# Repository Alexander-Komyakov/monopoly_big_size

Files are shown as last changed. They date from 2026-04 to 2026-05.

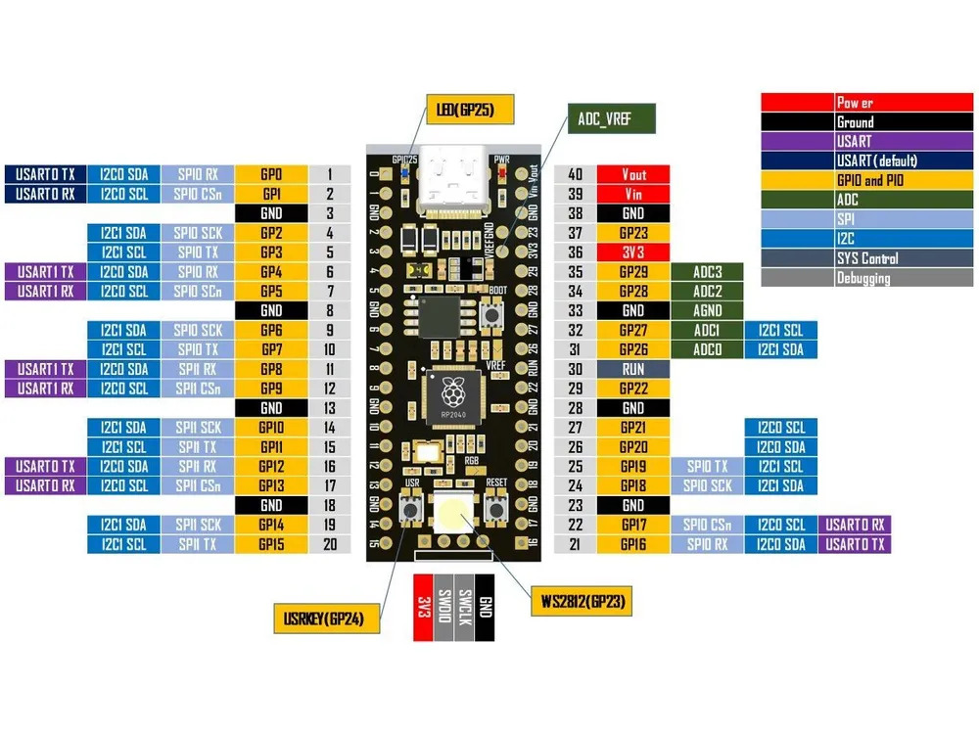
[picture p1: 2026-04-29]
pins.jpg

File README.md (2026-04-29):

# Банк монополии большего размера

Создан для упрощения игры. Вместо подсчета, размена и передачи бумажных купюр используются карточки. Их можно прикладывать для проверки баланса. Добавлять на них деньги, уменьшать или перводить. Для вывода информации используется экран `2,8` дюйма `240x320`. Для чтения карточек `RFID-RC522` и для ввода матричная клавиатура 4x4.

## Детали

- RFID-модуль Arduino RC522 с картой и брелоком 
- Матричная клавиатура 4x4
- Дисплей 2.8" 240x320, SPI
- Контроллер RP2040 TYPE-C 16MB
- Аккумулятор 3.3V 1000mAh
- TP4056 для безопасной зарядки/разрядки
- Переключатель трехконтактный

## Сборка

Зажимаем клавишу boot на rp2040 и подключаем usb. В ОС появится блочное устройство. Копируем на него firmware.uf2

Для сборки проекта устанавливаем python и зависимости из requirements.txt с помощью pip; `pip install -r requirements.txt`. Подключаем по microusb к компьютеру rp2040, при запуске зажимаем клавишу usr на 3 секунды. В системе появится девай `/dev/ttyACM0`
Далее с помощью mpremote копируем файлы на rp2040:
```
mpremote cp keypad.py :keypad.py
mpremote cp mfrc522.py :mfrc522.py
mpremote cp main.py :main.py
```

## Пайка

### Матричная панель

Слева направо напрямую подключаем пины к `rp2040` в `gp0,4,5,6,7,13,14,15`

### Дисплей

- VCC - 3.3V

- GND - GND

- LED = GP21

- RESET = GP20

- DC = GP12

- CS = GP1

- SCK = GP2

- MOSI = GP3

### RFID-RC522

- 3.3V - 3.3V

- GND - GND

- RST - GP22

- SDA - GP9

- SCK - GP10

- MOSI - GP11

- MISO - GP8

## Логика банка монополии:

Возможны три действия:
  1. Получение денег от банка
  2. Передача денег банку
  3. Передача денег между игроками
  4. Сброс до 1500 всем игрокам
  4. Запись новых карточек или запись карточек после сброса

### Получение денег от банка:
  Нажимаем плюс, пишем сумму, нажимаем апрув, прикладываем RFID метку, происходит запись

### Передача денег банку:
  Нажимаем минус, пишем сумму, нажимаем апрув, прикладываем RFID метку, происходит запись

  Если не хватает денег, то сообщает об этом и не происходит запись
  Баланс не может быть отрицательным

### Передача денег между игроками:
  Нажимаем на кнопку передачи денег, пишем передаваемую сумму, нажимаем апрув, прикладываем от кого, прикладываем кому, нажимаем апрув

  Если деньги у игрока закончились, то отмена операции и вывести сколько не хватает

### Запись новых карточек или запись карточек после сброса:
  Прикладываем карту, вводим от 1 до 8 число, нажимаем A. Теперь введеное число это номер игрока

### Кнопки:
'0-9' для написания числа

'D' - Стереть символ

'A' - Принять операцию - апрув - подтверждение

'#' - Минус

'*' - Плюс

'B' - Передача денег - действие

'C' - Отмена

Для сброса всех игроков на 1500 введите B99123A
Для сброса всех игроков на 1500 и сброса карточек игроков введите B99124A

### Печать

Для печати используем два файла в models. main и up stl
Включаем поддержки, 15% заполнение и печатаем

## Ссылки на источники:

_thread:
    https://www.electrosoftcloud.com/en/multithreaded-script-on-raspberry-pi-pico-and-micropython/

mfrc522-rfid:
    https://diyprojectslab.com/mfrc522-rfid-module-with-raspberry-pi-pico/

rp pico:
    https://datasheets.raspberrypi.com/pico/raspberry-pi-pico-python-sdk.pdf

micropython:
    https://github.com/micropython/micropython

keypad:
    https://github.com/PerfecXX/MicroPython-SimpleKeypad

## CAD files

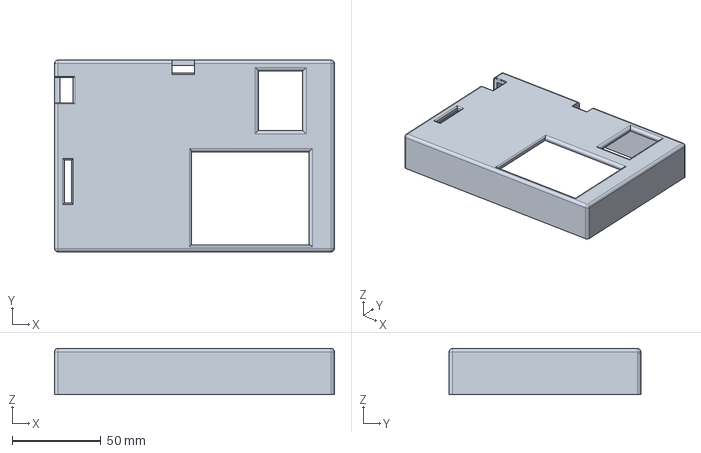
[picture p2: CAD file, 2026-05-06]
model/main.FCStd
157.5 x 107.9 x 26.0 mm

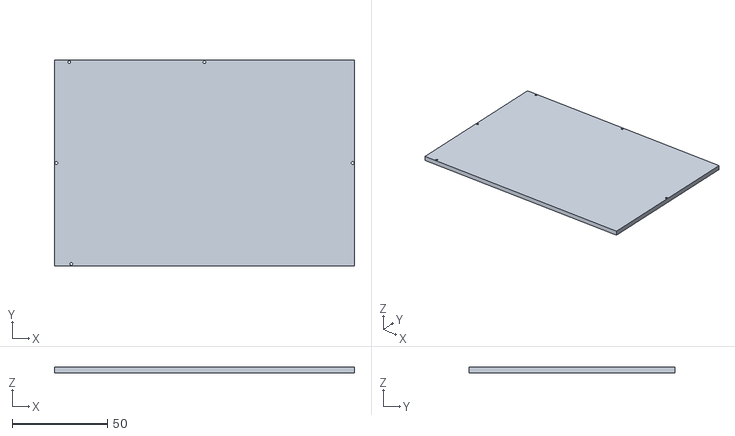
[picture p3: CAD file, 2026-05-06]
model/down.stl
157.5 x 107.9 x 3.00

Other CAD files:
model/main.stl

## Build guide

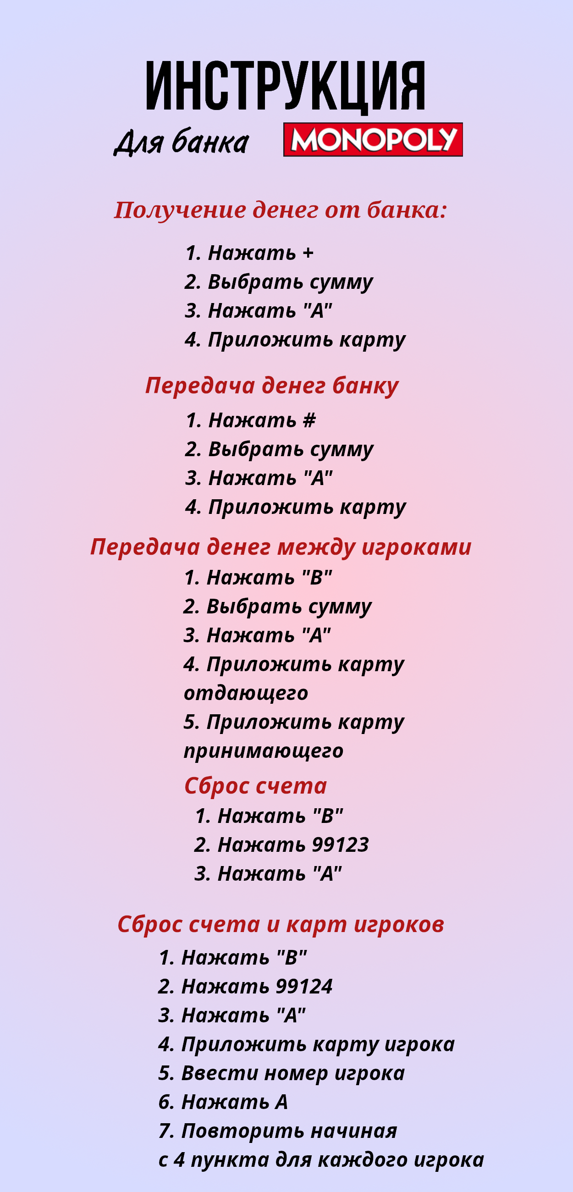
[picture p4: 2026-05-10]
images/instruction.png

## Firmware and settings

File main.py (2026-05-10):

from micropython import const
import framebuf
from machine import Pin, SoftI2C, SPI
import time
import utime
import os
from mfrc522 import MFRC522
from keypad import Keypad
import _thread
import st7789
import vga1_bold_16x32 as font



class Game:
    def __init__(self):
        self.COLOR_BG = st7789.color565(20, 120, 40)
        self.players = [1500, 1500, 1500, 1500, 1500, 1500, 1500, 1500]
        self.players_rfid = {"36046426852801050": 0, "36046426852800790": 1, "36046426852800540": 2, "36046426852800280": 3, "36046426852800020": 4, "36046426852799770": 5, "36046426852799510": 6, "36046426852799260": 7}
        
        self.load_from_file()
        
        self.state_game = "" # "" "plus1" "plus2" "minus1" "minus2" "trade1" "trade2" "trade3" "trade4"
        self.number = ""
        
        # Oled
        self.BACKLIGHT_PIN = 21
        self.RESET_PIN = 20
        self.DC_PIN = 12
        self.CS_PIN = 1
        self.CLK_PIN = 2
        self.DIN_PIN = 3

        self.spi = SPI(0, baudrate=31250000, sck=Pin(self.CLK_PIN), mosi=Pin(self.DIN_PIN))
        self.oled_width = 240
        self.oled_height = 320
        self.tft = st7789.ST7789(self.spi, self.oled_width, self.oled_height,
            reset=Pin(self.RESET_PIN, Pin.OUT),
            cs=Pin(self.CS_PIN, Pin.OUT),
            dc=Pin(self.DC_PIN, Pin.OUT),
            backlight=Pin(self.BACKLIGHT_PIN, Pin.OUT),
            rotation=4)
        self.tft.init()

        # RFID
        self.rfid_reader = MFRC522(spi_id=1, sck=10, miso=8, mosi=11, cs=9, rst=22)
        self.rfid_reader.init()

        # Keypad
        # Define GPIO pins for rows
        self.row_pins = [Pin(0),Pin(4),Pin(5),Pin(6)]
        # Define GPIO pins for columns
        self.column_pins = [Pin(7),Pin(13),Pin(14),Pin(15)]
        # Define keypad layout
        self.keys = [
            ['1', '2', '3', 'A'],
            ['4', '5', '6', 'B'],
            ['7', '8', '9', 'C'],
            ['*', '0', '#', 'D']]

        self.keypad = Keypad(self.row_pins, self.column_pins, self.keys)
        

    def replace_rfid_by_index(self, target_index, new_rfid):
        for rfid, index in self.players_rfid.items():
            if index == target_index:
                del self.players_rfid[rfid]
                self.players_rfid[new_rfid] = target_index
                break
    def load_from_file(self):
        try:
            with open('save.txt', 'r') as f:
                for i in range(0, 8):
                    self.players[i] = int((f.readline())[:-1])
                self.players_rfid = {}
                for i in range(0, 8):
                    self.players_rfid[(f.readline())[:-1]] = i
        except:
            with open('save.txt', 'w') as f:
                for i in range(0, 7):
                    f.write('1500\n')
                    self.players[i] = 1500

            players_sorted = sorted(self.players_rfid.items(), key=lambda x: x[1])
            with open('save.txt', 'a') as f:
                for rfid, index in players_sorted:
                    f.write(f"{rfid}\n")
    
    def save_to_file(self):
        with open('save.txt', 'w') as f:
            for i in range(0, 8):
                f.write(f"{self.players[i]}\n")

        players_sorted = sorted(self.players_rfid.items(), key=lambda x: x[1])
        with open('save.txt', 'a') as f:
            for rfid, index in players_sorted:
                f.write(f"{rfid}\n")
                
    def keypad_thread(self):
        state = False
        while True:
            key_pressed = self.keypad.read_keypad()
            if (key_pressed != None) and (state == False):
                if key_pressed == "D": #trade
                    if self.state_game == "trade1" and len(self.number) > 0:
                        self.number = self.number[:-1]
                        self.show_trade(self.number)
                    if self.state_game == "minus1" and len(self.number) > 0:
                        self.number = self.number[:-1]
                        self.show_minus(self.number)
                    if self.state_game == "plus1" and len(self.number) > 0:
                        self.number = self.number[:-1]
                        self.show_plus(self.number)
                if key_pressed == "B": #trade
                    self.number = ""
                    self.state_game = "trade1"
                    self.show_trade(self.number)
                if key_pressed == "C": #break
                    self.show_score_all()
                    self.state_game = ""
                    self.number = ""
                if key_pressed == "#": #minus
                    self.number = ""
                    self.state_game = "minus1"
                    self.show_minus(self.number)
                if key_pressed == "*": #plus
                    self.number = ""
                    self.state_game = "plus1"
                    self.show_plus(self.number)
                if key_pressed in ("0", "1", "2", "3", "4", "5", "6", "7", "8", "9"):
                    if self.state_game == "plus1" and len(self.number) < 5:
                        self.number = self.number + key_pressed
                        self.show_plus(self.number)
                    if self.state_game == "minus1" and len(self.number) < 5:
                        self.number = self.number + key_pressed
                        self.show_minus(self.number)
                    if self.state_game == "trade1" and len(self.number) < 5:
                        self.number = self.number + key_pressed
                        self.show_trade(self.number)
                    if self.state_game == "setRfid":
                        self.number = key_pressed
                        self.tft.text(font, f"{self.number}", 80, 100, st7789.color565(255,255,255), self.COLOR_BG)
                if key_pressed == "A": #approve
                    if self.state_game == "setRfid":
                        if self.number in ("1", "2", "3", "4", "5", "6", "7", "8"):
                            self.state_game = ""
                            self.replace_rfid_by_index(int(self.number)-1, self.save_rfid)
                            self.save_to_file()
                            self.load_from_file()
                            self.show_score_all()
                    if self.state_game == "plus1":
                        if self.number != "":
                            self.state_game = "plus2"
                            self.number = self.number + "A"
                            self.show_plus(self.number)
                        else:
                            self.show_score_all()
                            self.state_game = ""
                            self.number = ""
                    if self.state_game == "minus1":
                        if self.number != "":
                            self.state_game = "minus2"
                            self.number = self.number + "A"
                            self.show_minus(self.number)
                        else:
                            self.show_score_all()
                            self.state_game = ""
                            self.number = ""
                    if self.state_game == "trade1":
                        if self.number != "":
                            self.state_game = "trade2"
                            self.number = self.number + "A"
                            self.show_trade(self.number)
                            #restore game
                            if self.number == "99123A":
                                self.players = [1500]*8
                                self.save_to_file()
                                self.number = ""
                                self.state_game = ""
                                self.show_score_all()
                            elif self.number == "99124A":
                                self.players = [1500]*8
                                self.players_rfid = {"36046426852801050": 0, "36046426852800790": 1, "36046426852800540": 2, "36046426852800280": 3, "36046426852800020": 4, "36046426852799770": 5, "36046426852799510": 6, "36046426852799260": 7}
                                self.save_to_file()
                                self.load_from_file()
                                self.number = ""
                                self.state_game = ""
                                self.show_score_all()
                        else:
                            self.show_score_all()
                            self.state_game = ""
                            self.number = ""
                    
                state = True
            elif key_pressed == None:
                state = False

    def run_game(self):
        _thread.start_new_thread(self.keypad_thread, ())
        self.show_score_all()
        while True:
            (card_status, tag_type) = self.rfid_reader.request(self.rfid_reader.REQIDL)
            if card_status == self.rfid_reader.OK:
                (card_status, card_id) = self.rfid_reader.SelectTagSN()
                if card_status == self.rfid_reader.OK:
                    rfid_card = str(int.from_bytes(bytes(card_id),"little",False))
                    if rfid_card in self.players_rfid.keys():
                        player_id = self.players_rfid[rfid_card]
                        if self.state_game == "plus2":
                            self.players[player_id] = self.players[player_id] + int(self.number[:-1])
                            self.save_to_file()
                            self.state_game = ""
                            self.number = ""
                            self.show_score_one(player_id)
                        elif self.state_game == "minus2":
                            if (self.players[player_id] - int(self.number[:-1])) >= 0:
                                self.players[player_id] = self.players[player_id] - int(self.number[:-1])
                                self.save_to_file()
                                self.state_game = ""
                                self.number = ""
                                self.show_score_one(player_id)
                            else:
                                self.show_not_enough(self.players[player_id] - int(self.number[:-1]))
                                self.state_game = ""
                                self.number = ""
                        elif self.state_game == "trade2":
                            if (self.players[player_id] - int(self.number[:-1])) >= 0:
                                self.save_player_id_trade = player_id
                                self.show_score_one_number((self.players[player_id] - int(self.number[:-1])))
                                self.state_game = "trade3"
                            else:
                                self.show_not_enough(self.players[player_id] - int(self.number[:-1]))
                                self.state_game = ""
                                self.number = ""
                        elif self.state_game == "trade3":
                            self.players[self.save_player_id_trade] = self.players[self.save_player_id_trade] - int(self.number[:-1])
                            self.players[player_id] = self.players[player_id] + int(self.number[:-1])
                            self.save_to_file()
                            self.state_game = ""
                            self.number = ""
                            self.show_score_one(player_id)
                            self.save_player_id_trade = -1
                        else:
                            self.show_score_one(player_id)
                    else:
                        self.tft.fill(self.COLOR_BG)
                        self.tft.text(font, "Type number", 10, 20, st7789.color565(255,255,255), self.COLOR_BG)
                        self.tft.text(font, "new player", 10, 60, st7789.color565(255,255,255), self.COLOR_BG)
                        self.tft.text(font, "1-8:", 10, 100, st7789.color565(255,255,255), self.COLOR_BG)
                        self.state_game = "setRfid"
                        self.save_rfid = rfid_card
    
    def show_score_all(self):
        self.tft.fill(self.COLOR_BG)
        for i in range(0, 8):
            self.tft.text(font, f"{i+1}: {self.players[i]}", 10, i*40, st7789.color565(255,255,255), self.COLOR_BG)
    
    def show_score_one(self, player):
        self.tft.fill(self.COLOR_BG)
        for i in range(0, 8):
            if player == i:
                self.tft.text(font, f"{i+1}: {self.players[i]}", 10, i*40, st7789.color565(0,255,255), self.COLOR_BG)
            else:
                self.tft.text(font, f"{i+1}: {self.players[i]}", 10, i*40, st7789.color565(255,255,255), self.COLOR_BG)
        
    def show_score_one_number(self, number):
        self.tft.fill(self.COLOR_BG)
        if number > 99999:
            self.tft.text(font, str(number), 10, 20, st7789.color565(255,255,255), self.COLOR_BG)
        else:    
            self.tft.text(font, str(number), 10, 20, st7789.color565(255,255,255), self.COLOR_BG)
    
    def show_trade(self, number):
        self.tft.fill(self.COLOR_BG)
        self.tft.text(font, f"T{number}", 10, 20, st7789.color565(255,255,255), self.COLOR_BG)
    
    def show_plus(self, number):
        self.tft.fill(self.COLOR_BG)
        self.tft.text(font, f"+{number}", 10, 20, st7789.color565(255,255,255), self.COLOR_BG)
    
    def show_minus(self, number):
        self.tft.fill(self.COLOR_BG)
        self.tft.text(font, f"-{number}", 10, 20, st7789.color565(255,255,255), self.COLOR_BG)
    
    def show_not_enough(self, number):
        self.tft.fill(self.COLOR_BG)
        if int(self.number[:-1]) > 9999:
            self.tft.text(font, f"NO {number}", 10, 20, st7789.color565(255,255,255), self.COLOR_BG)
        else:
            self.tft.text(font, f"NO {number}", 10, 20, st7789.color565(255,255,255), self.COLOR_BG)

game = Game()
game.run_game()

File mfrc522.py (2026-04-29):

# credit: https://github.com/danjperron/micropython-mfrc522

from machine import Pin, SPI
from os import uname


class MFRC522:

    DEBUG = False
    OK = 0
    NOTAGERR = 1
    ERR = 2

    REQIDL = 0x26
    REQALL = 0x52
    AUTHENT1A = 0x60
    AUTHENT1B = 0x61
  
    PICC_ANTICOLL1 = 0x93
    PICC_ANTICOLL2 = 0x95
    PICC_ANTICOLL3 = 0x97
  

    def __init__(self, sck, mosi, miso, rst, cs,baudrate=1000000,spi_id=0):

        self.sck = Pin(sck, Pin.OUT)
        self.mosi = Pin(mosi, Pin.OUT)
        self.miso = Pin(miso)
        self.rst = Pin(rst, Pin.OUT)
        self.cs = Pin(cs, Pin.OUT)

        self.rst.value(0)
        self.cs.value(1)
        
        board = uname()[0]

        if board == 'WiPy' or board == 'LoPy' or board == 'FiPy':
            self.spi = SPI(0)
            self.spi.init(SPI.MASTER, baudrate=1000000, pins=(self.sck, self.mosi, self.miso))
        elif (board == 'esp8266') or (board == 'esp32'):
            self.spi = SPI(baudrate=100000, polarity=0, phase=0, sck=self.sck, mosi=self.mosi, miso=self.miso)
            self.spi.init()
        elif board == 'rp2':
            self.spi = SPI(spi_id,baudrate=baudrate,sck=self.sck, mosi= self.mosi, miso= self.miso)
        else:
            raise RuntimeError("Unsupported platform")

        self.rst.value(1)
        self.init()

    def _wreg(self, reg, val):

        self.cs.value(0)
        self.spi.write(b'%c' % int(0xff & ((reg << 1) & 0x7e)))
        self.spi.write(b'%c' % int(0xff & val))
        self.cs.value(1)

    def _rreg(self, reg):

        self.cs.value(0)
        self.spi.write(b'%c' % int(0xff & (((reg << 1) & 0x7e) | 0x80)))
        val = self.spi.read(1)
        self.cs.value(1)

        return val[0]

    def _sflags(self, reg, mask):
        self._wreg(reg, self._rreg(reg) | mask)

    def _cflags(self, reg, mask):
        self._wreg(reg, self._rreg(reg) & (~mask))

    def _tocard(self, cmd, send):

        recv = []
        bits = irq_en = wait_irq = n = 0
        stat = self.ERR

        if cmd == 0x0E:
            irq_en = 0x12
            wait_irq = 0x10
        elif cmd == 0x0C:
            irq_en = 0x77
            wait_irq = 0x30

        self._wreg(0x02, irq_en | 0x80)
        self._cflags(0x04, 0x80)
        self._sflags(0x0A, 0x80)
        self._wreg(0x01, 0x00)

        for c in send:
            self._wreg(0x09, c)
        self._wreg(0x01, cmd)

        if cmd == 0x0C:
            self._sflags(0x0D, 0x80)

        i = 2000
        while True:
            n = self._rreg(0x04)
            i -= 1
            if ~((i != 0) and ~(n & 0x01) and ~(n & wait_irq)):
                break

        self._cflags(0x0D, 0x80)

        if i:
            if (self._rreg(0x06) & 0x1B) == 0x00:
                stat = self.OK

                if n & irq_en & 0x01:
                    stat = self.NOTAGERR
                elif cmd == 0x0C:
                    n = self._rreg(0x0A)
                    lbits = self._rreg(0x0C) & 0x07
                    if lbits != 0:
                        bits = (n - 1) * 8 + lbits
                    else:
                        bits = n * 8

                    if n == 0:
                        n = 1
                    elif n > 16:
                        n = 16

                    for _ in range(n):
                        recv.append(self._rreg(0x09))
            else:
                stat = self.ERR

        return stat, recv, bits

    def _crc(self, data):

        self._cflags(0x05, 0x04)
        self._sflags(0x0A, 0x80)

        for c in data:
            self._wreg(0x09, c)

        self._wreg(0x01, 0x03)

        i = 0xFF
        while True:
            n = self._rreg(0x05)
            i -= 1
            if not ((i != 0) and not (n & 0x04)):
                break

        return [self._rreg(0x22), self._rreg(0x21)]

    def init(self):

        self.reset()
        self._wreg(0x2A, 0x8D)
        self._wreg(0x2B, 0x3E)
        self._wreg(0x2D, 30)
        self._wreg(0x2C, 0)
        self._wreg(0x15, 0x40)
        self._wreg(0x11, 0x3D)
        self.antenna_on()

    def reset(self):
        self._wreg(0x01, 0x0F)

    def antenna_on(self, on=True):

        if on and ~(self._rreg(0x14) & 0x03):
            self._sflags(0x14, 0x03)
        else:
            self._cflags(0x14, 0x03)

    def request(self, mode):

        self._wreg(0x0D, 0x07)
        (stat, recv, bits) = self._tocard(0x0C, [mode])

        if (stat != self.OK) | (bits != 0x10):
            stat = self.ERR

        return stat, bits
  
    def anticoll(self,anticolN):

        ser_chk = 0
        ser = [anticolN, 0x20]

        self._wreg(0x0D, 0x00)
        (stat, recv, bits) = self._tocard(0x0C, ser)

        if stat == self.OK:
            if len(recv) == 5:
                for i in range(4):
                    ser_chk = ser_chk ^ recv[i]
                if ser_chk != recv[4]:
                    stat = self.ERR
            else:
                stat = self.ERR

        return stat, recv
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
